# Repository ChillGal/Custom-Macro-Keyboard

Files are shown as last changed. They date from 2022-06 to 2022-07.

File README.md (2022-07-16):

# Custom-Macro-Keyboard
Custom designed macro keyboard

Thingiverse: https://www.thingiverse.com/thing:5415824

This was personal project for my partner as he is a streamer and the extra keys to bind to use is very useful while being cheaper than a Elgato stream deck.
- The case was designed in Autodesk Fusion 360.
- Code written in Arduino IDE.

## Part choice
For this project, I knew I wanted a display for text, a volume control knob and at least 8 buttons. The buttons also had to have a nice feeling so i went with Cherry MX Brown switches as they are my partner's favourite kind of switch. I used re-legendable keycaps to allow for relabelling the keycaps at a later date if necessary. The components used in this project are:
- Arduino Pro Micro (I specifically looked for a USB-C version since it is most robust than USB-B Micro and reversible connector)
- Rotary Encoders with threads (KY-040) to mount to the base plate
- Cherry MX Brown switches (I bought a pack of 30 for future project use)
- 0.91" OLED i2C module (Black & White)
- USB-C Female Breakout board (To mount to the Base)
- USB-C Male connector (To prevent wear and tear to the USB-C port built on the arduino)
- Solid core wire (Various colours to aid in organisation)
- M3 Screws (To mount the key plate)
- M3 Threaded Inserts (To allow the screws to mount)
- Rubber feet (to stop the keyboard moving so much when keys are pressed)

## Tools
To finish this project, the following tools were used which I consider essential:
- Soldering Iron
- 3D Printer (Creality CR-10S-Pro Stock) with PLA filament
- Screwdriver
- Wire cutters (Or scissors)
- A device capable of flashing code to the arduino
- Super Glue (for holding the display in place without moving)
- Heatshrink tubing (Prevent shorts)

Nice to haves:
- Label maker (For keycaps)
- Hot air gun (To soften the PLA and activate the heat shrink)
- Sandpaper (To give a nicer finish)
- 

## Design
The design of the case was done in Fusion Autodesk 360 over 8 iterations. It has an angle of 45&deg; for the keyplate with the keyplate while the display is mounted at a slightly steeper 60&deg; angle. The key spacing between the keys is to the Cherry specification of 19mm centre to centre.

### Keyboard base
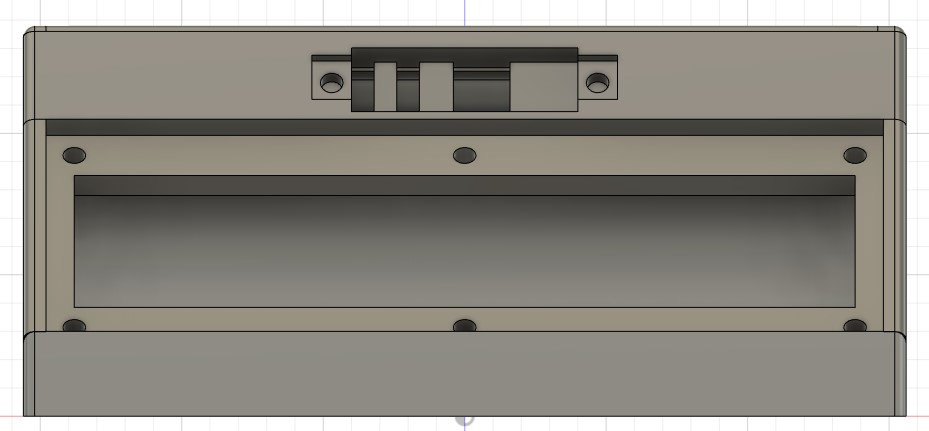
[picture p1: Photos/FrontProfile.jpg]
Front view of the base

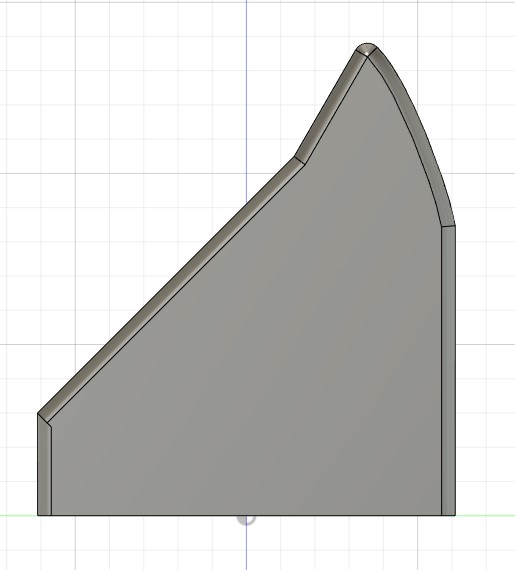
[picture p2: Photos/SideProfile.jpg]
Side view of the base

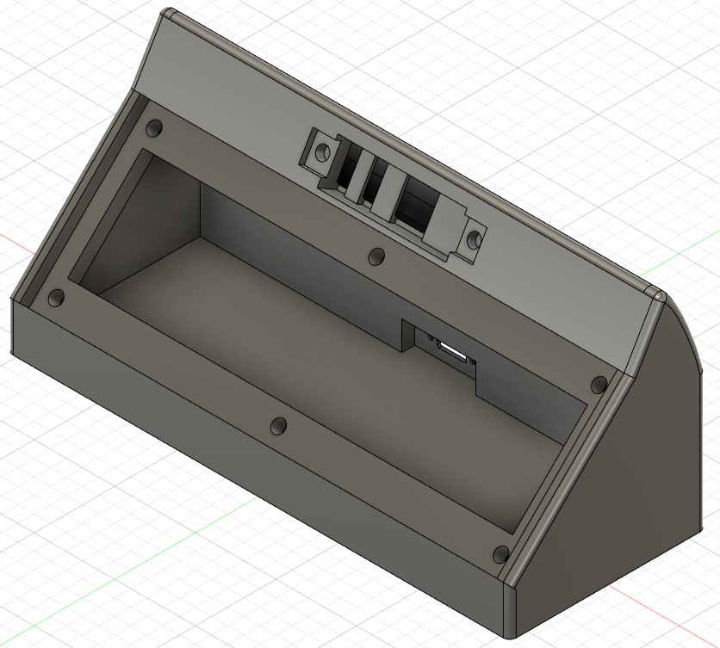
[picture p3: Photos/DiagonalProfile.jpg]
Diagonal view of the base

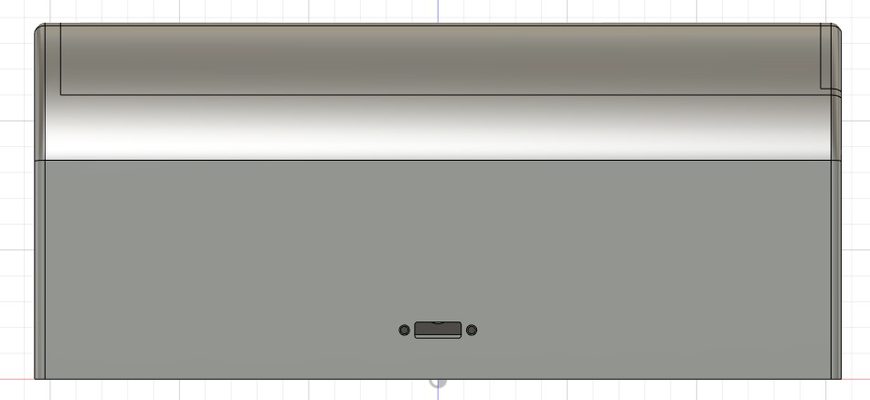
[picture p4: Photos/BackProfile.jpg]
Back view of the base


### Key plate
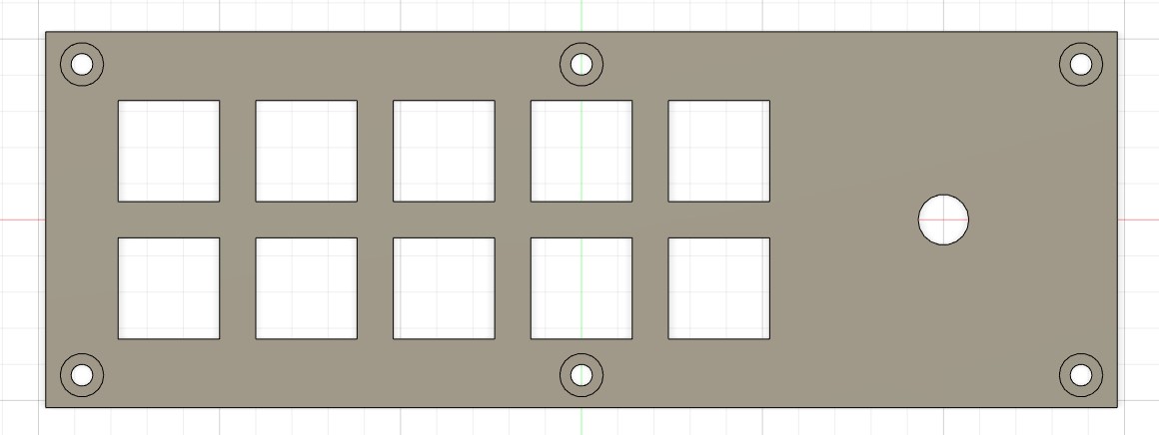
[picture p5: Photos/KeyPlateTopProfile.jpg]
Top view of the key plate

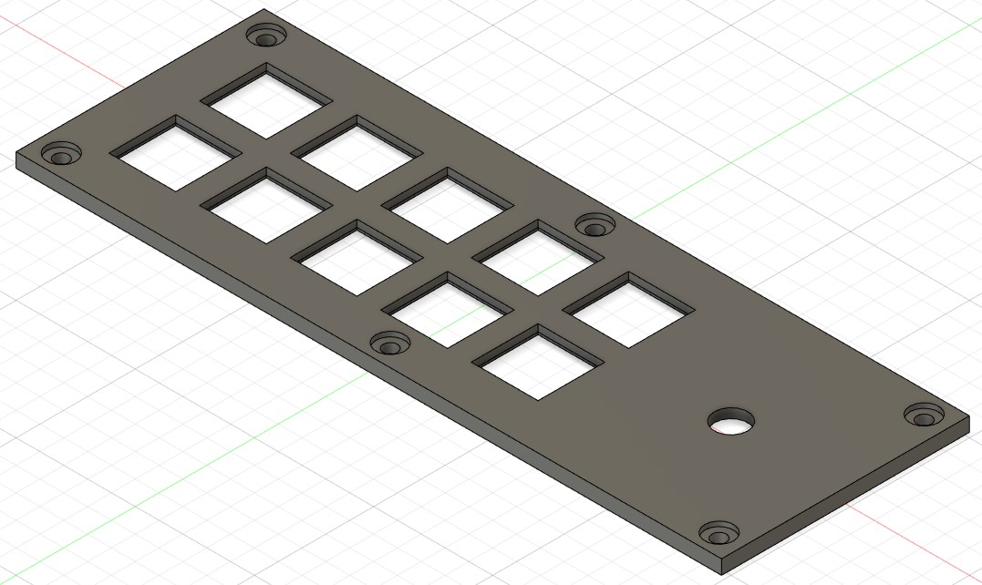
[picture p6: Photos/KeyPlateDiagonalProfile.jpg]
Diagonal view of the key plate


### Display plate
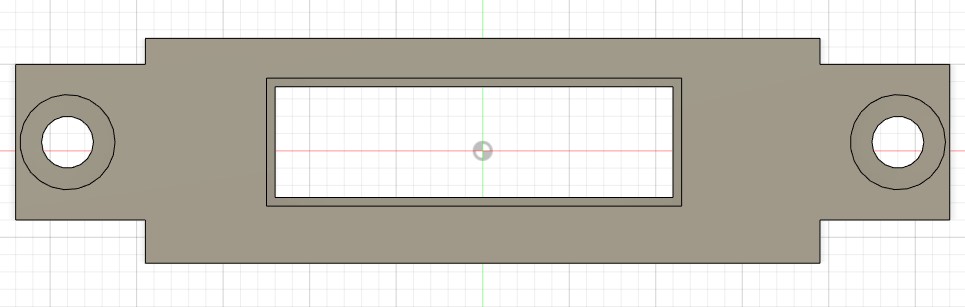
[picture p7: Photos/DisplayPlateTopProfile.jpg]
Top view of the display plate

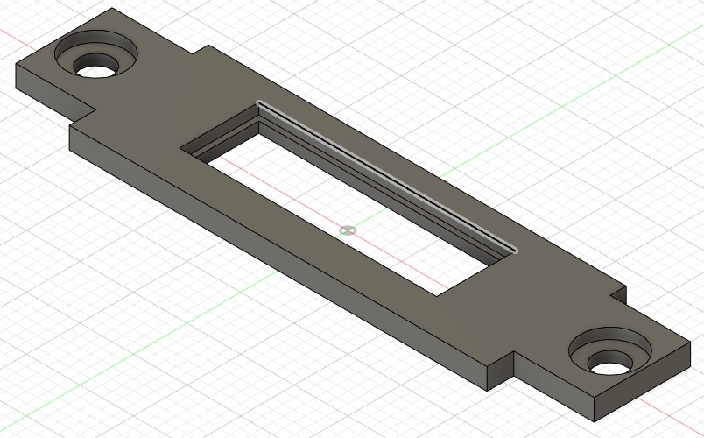
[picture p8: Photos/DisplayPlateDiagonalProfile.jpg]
Diagonal view of the display plate


## Printing the parts
This took a ridiculous amount of time at 18 hours to print for the base alone. The display plate took 20 minutes and the Keyplate took about 2$\frac{1}{2}$ hours resulting in a total print time of 20 hours and 50 minutes not including prototype prints. The base also printed with a lot of support which took a significant time to remove. In addition, I did not have good printer bed adhesion and as such used copious amount of glue to get the first layer to stick, however this glue resulted in lots of unevenness on the bottom which was luckily sorted out by the use of rubber feet on the corners.

## Soldering

### The arduino pins
I chose to solder pins rather than headers to the pcb so that i could easily hotswap it incase of failures since it is much easier to unplug 2 big headers than lots of small pins in order to take out the arduino. Another advantage is the size taken up by the pins which is significantly smaller height wise allowing to fit into the case without issue.

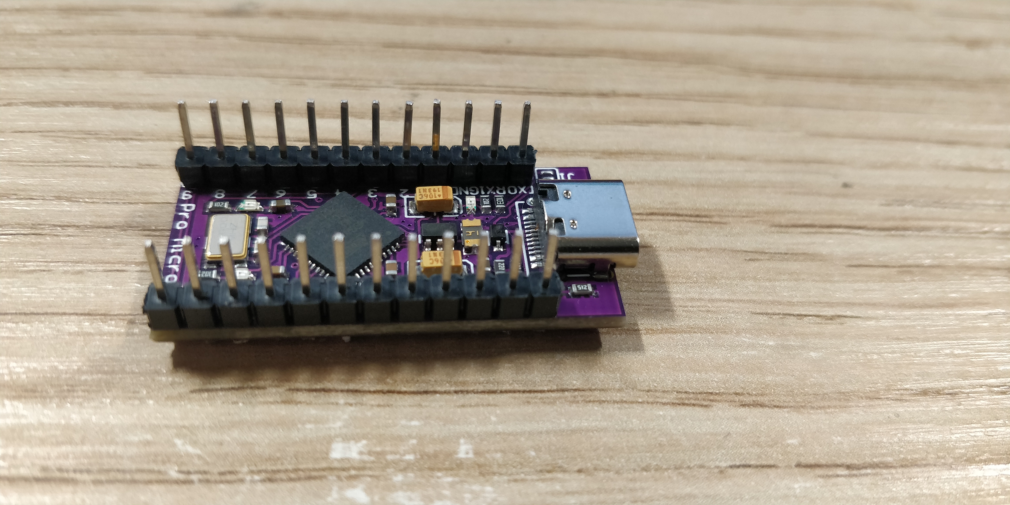
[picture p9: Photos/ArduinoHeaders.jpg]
Soldered Pins rather than headers

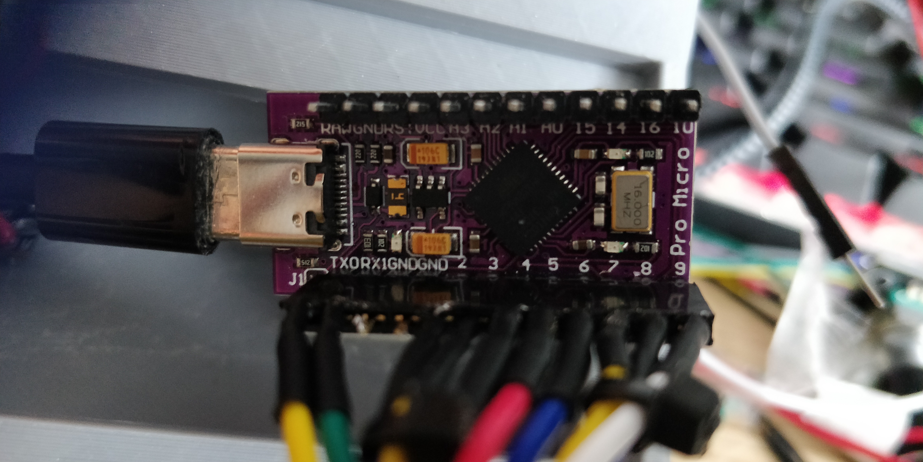
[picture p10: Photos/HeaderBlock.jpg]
A header block being used to connect the various parts of the project to the arduino

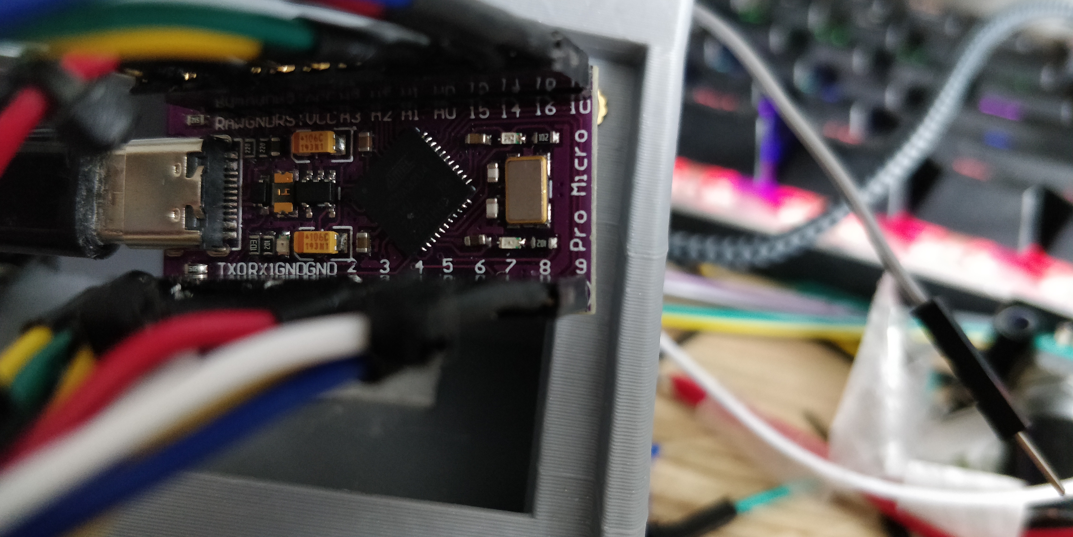
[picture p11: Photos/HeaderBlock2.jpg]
Closeup of headers blocks used


### Switch wiring
Initially all the switches were connected individually. However it was not a robust enough solution since the switch pins would fatigue from the constant movement and break easily. Therefore, I used solid core wire and twisted them together to make the entire assembly less prone to wear and be a lot stronger as a result. This also solved the issue of too many ground cables. The entire plate now just uses 1 ground connection which comes from the rotary encoder. Much better than 11 ground wires which I originally had. Each switch was connected to a pin on the pro micro which was pulled up and allowed for key press detection.

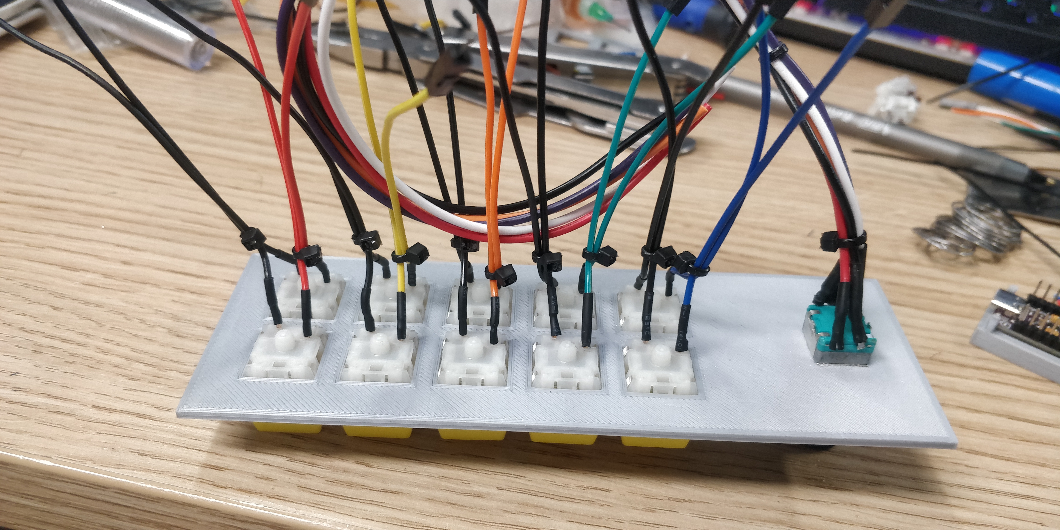
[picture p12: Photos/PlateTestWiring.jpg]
Initial Switch and enoder mounting with test leads

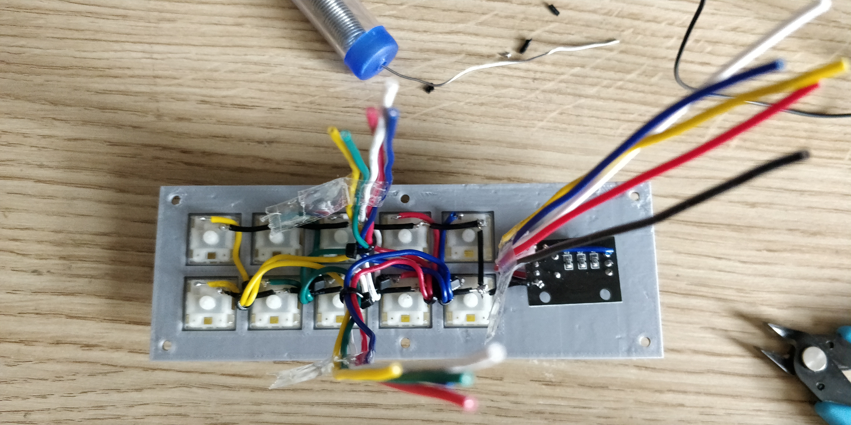
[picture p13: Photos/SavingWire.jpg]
Wires sorted into 3 bundles for top and bottom row and the encoder

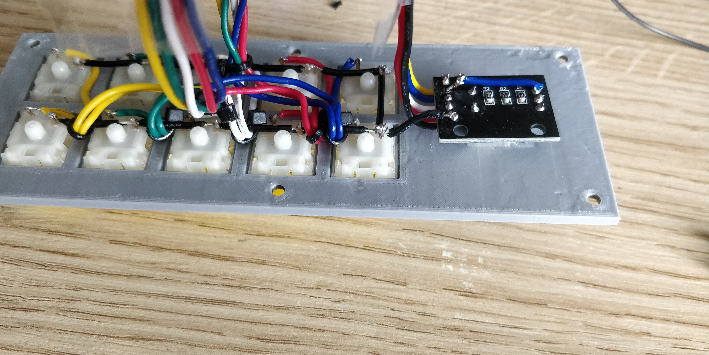
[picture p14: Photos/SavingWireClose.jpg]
Ground is shared across all buttons


### Display wiring
Since I had not fully assembled the project when I was testing the display, I used a header block to allow me to easily plug and unplug the display.

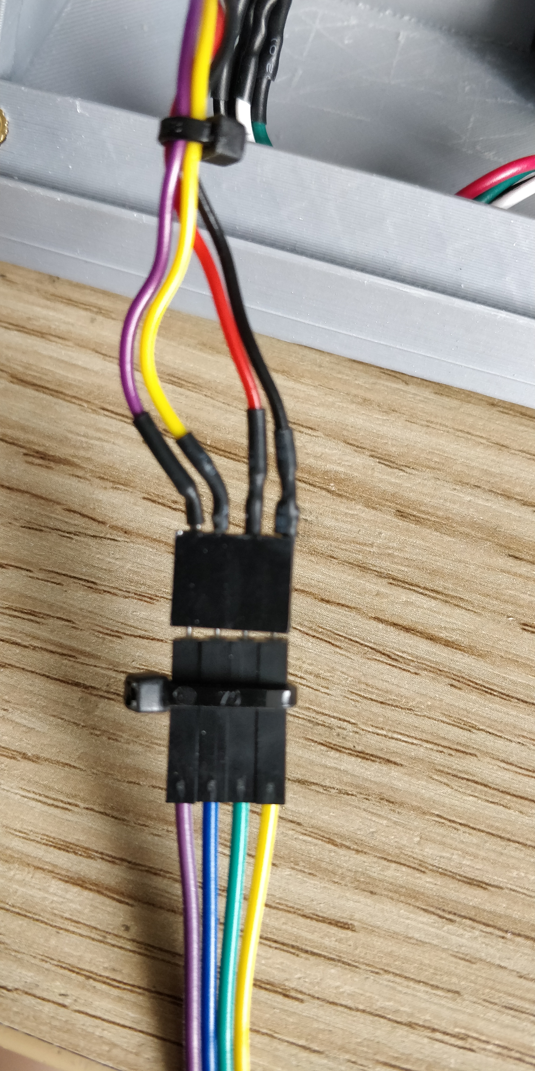
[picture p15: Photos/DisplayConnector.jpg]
Header connected to the display to allow for quick plug and unplugging


### USB wiring
Since the arduino only supports USB 2.0 Speeds, there is no point in increasing complexity and cost to get a USB 3.0 Type C connector.
From Left to right on the image below:
- Black = Ground
- Green = Data-
- White = Data+
- Red = 5V
USB-C Wiring

## Assembly

### Wiring
As a test fit, I tried putting everything in the base but the wires were too long so they needed to be shortened for the actual assembly.

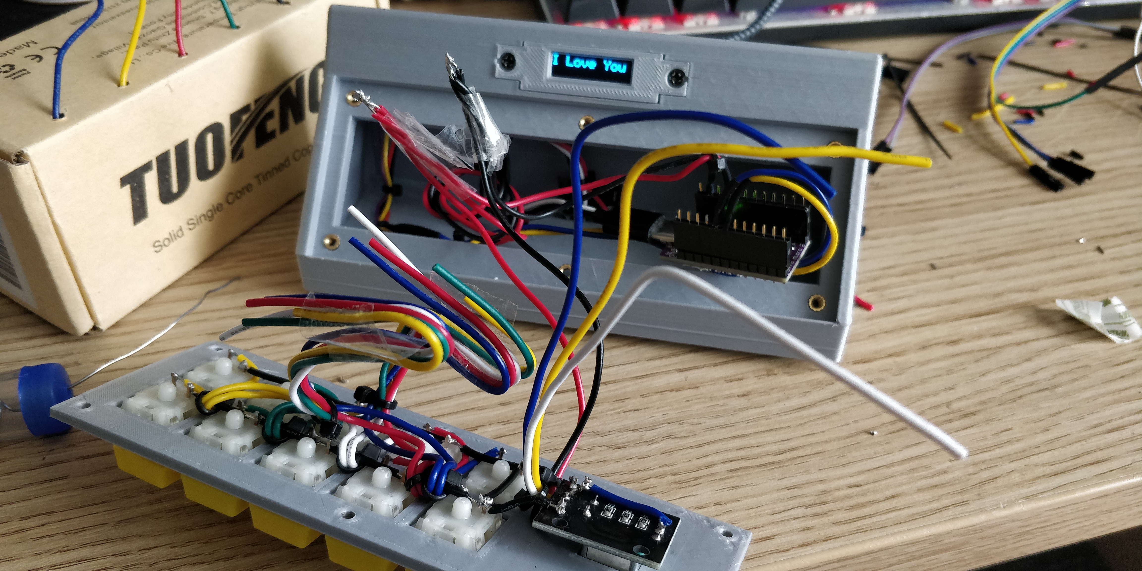
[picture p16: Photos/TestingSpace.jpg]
Trying to cram all the wires into the base


### Key plate
The switches fit snugly into the mounts and the encoder is secured with a washer and nut which is hidden beneath the knob. Screw holes were added to mount the plate to the base.

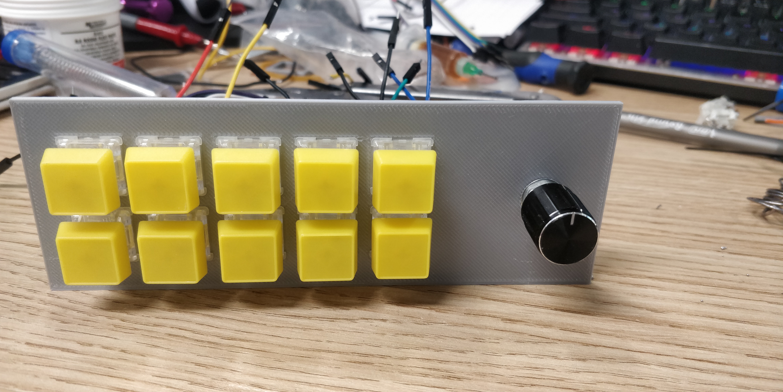
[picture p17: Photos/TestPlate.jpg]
Test fitting the keys and encoder

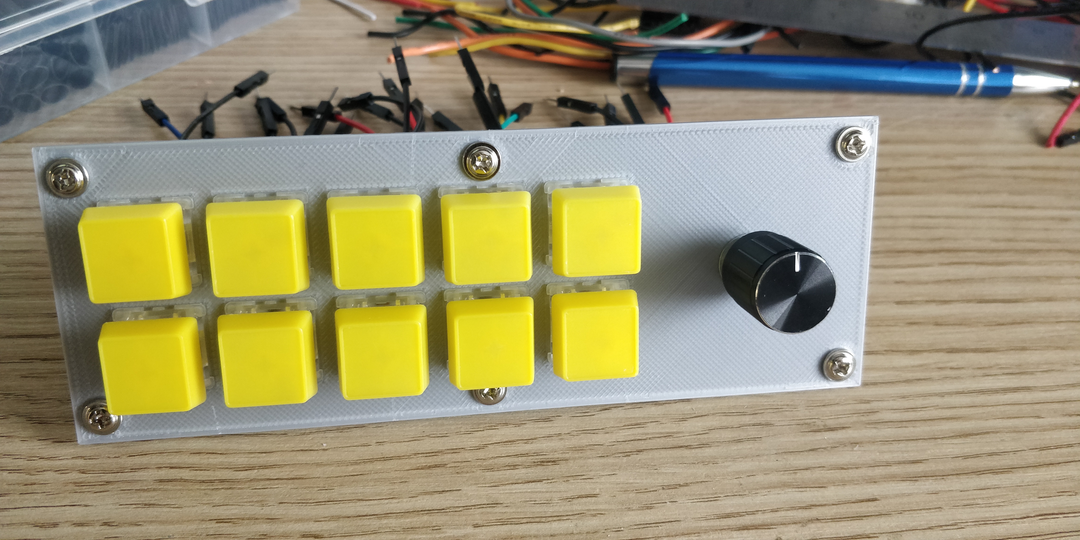
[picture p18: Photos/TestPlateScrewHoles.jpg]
Added screw holes which were later counter sunk to allow screws to sit flush


### Mounting the arduino
Since i had soldered the pins to the arduino, this came with some concerns. Mainly the worry that the pins could come in contact with a metal surface and short out which is particulary dangerous since it could kill the arduino. To prevent this, I came up with a small base plate that the arduino will slot into and sit on while the project was being developed. In the actual case, it is attached with some command strips between the pcb and the floor of the base.

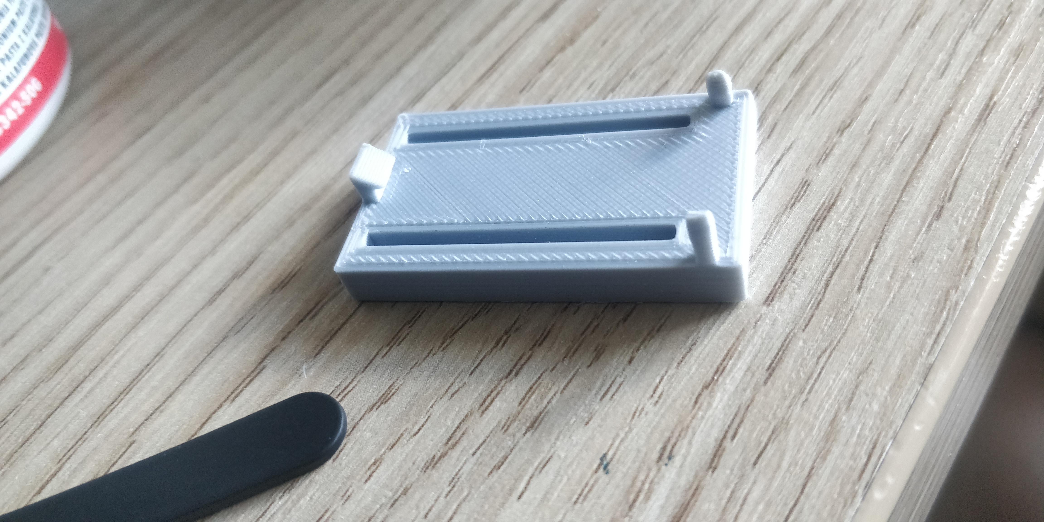
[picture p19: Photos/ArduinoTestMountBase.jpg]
Arduino was mounted in here

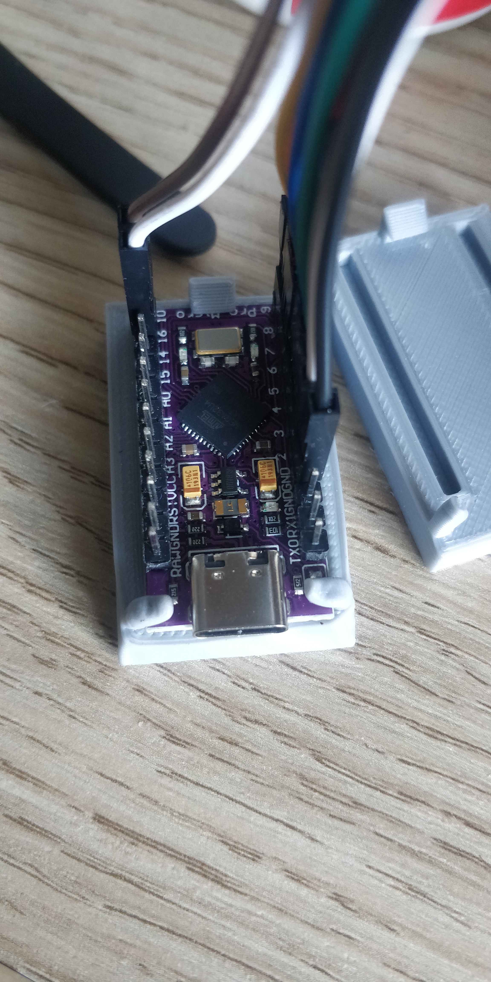
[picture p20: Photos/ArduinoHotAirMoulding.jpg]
A hot air gun was used to soften the PLA allowing me to manipulate it to a shape that holds the arduino more securely


## End Result
The final result of assembly. The screws were swapped out to smaller headed M3 threaded ones to allow for a flush fit. Personally, I think it looks better this way. Behind each screw is a threaded insert that was pushed into the PLA using the soldering iron.
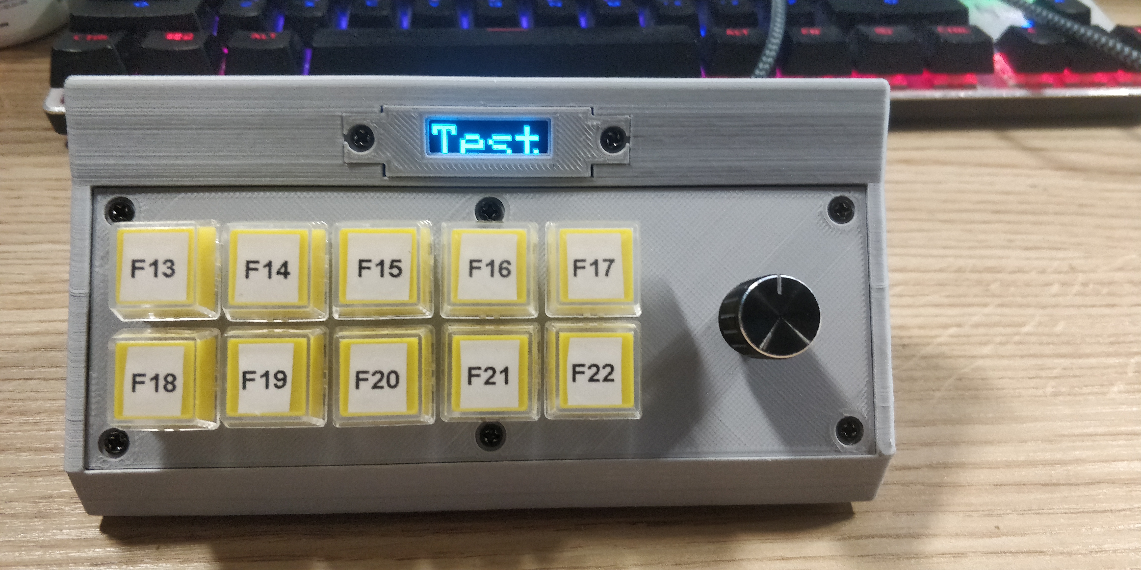
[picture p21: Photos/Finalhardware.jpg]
Final result


## Conclusion
Overall, this was a very fun project which was also very rewarding. However there are a number of things that I would change if I was to do this again, these being:
- The overall finish of the base should be smoother and the bottom should not be uneven to give a more appealing look.
- The weight of the base should be heavier to stop it moving around easily as the buttons and encoder are used.
- The angle of the buttons should be less agressive as it places quite a bit of stress on the wrist if used intensively for prolonged periods. 
- A bigger display which would allow for more details to be shown.

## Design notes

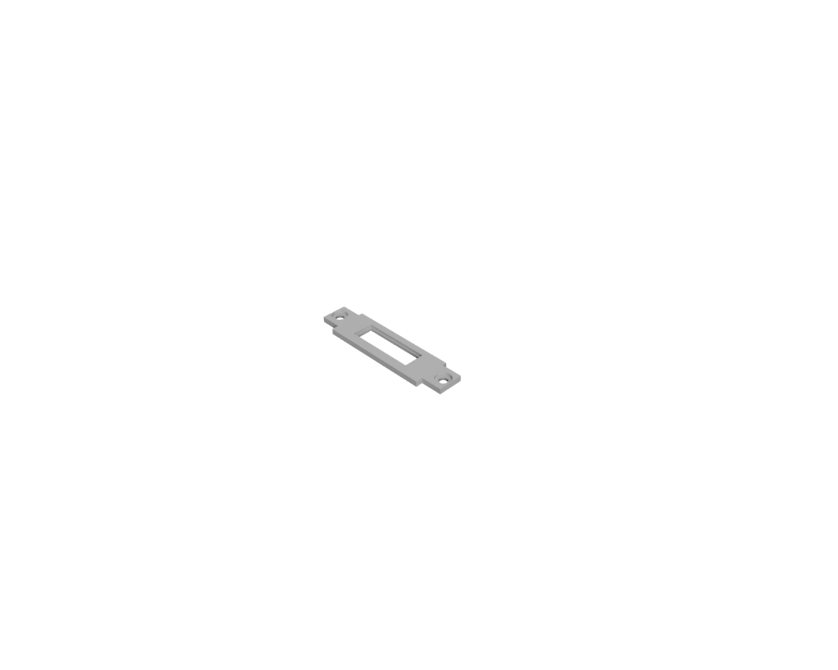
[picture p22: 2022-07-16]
Photos/DisplayPlateRender.png

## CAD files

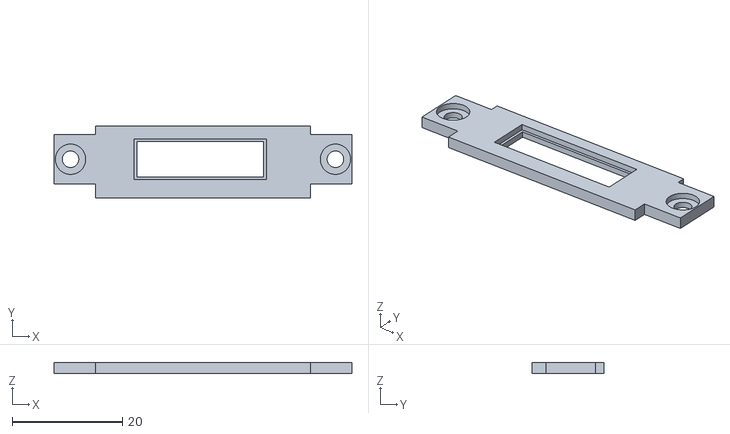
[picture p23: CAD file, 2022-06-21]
Macro-Keyboard-DisplayPlate.stl
54.0 x 13.0 x 2.00

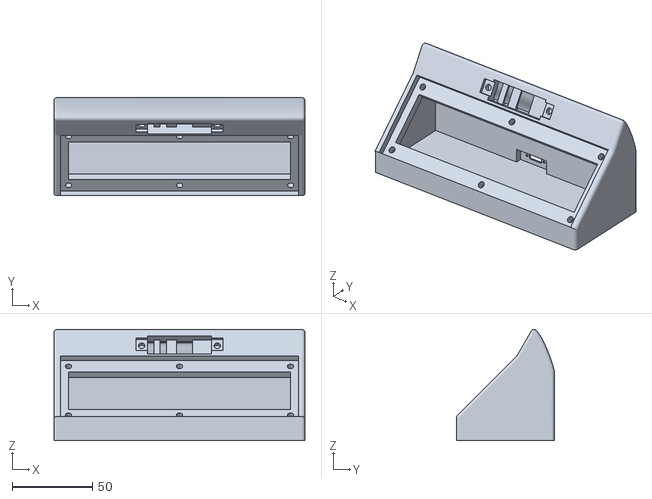
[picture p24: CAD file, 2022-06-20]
Macro-Keyboard-Base.stl
156.0 x 61.0 x 69.0

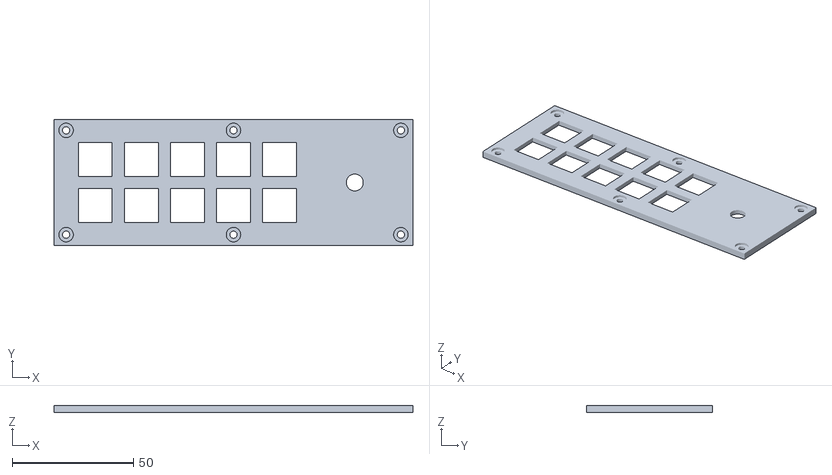
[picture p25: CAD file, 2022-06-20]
Macro-Keyboard-Keyplate.stl
148.0 x 52.0 x 3.00

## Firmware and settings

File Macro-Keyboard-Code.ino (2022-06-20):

#include <Adafruit_GFX.h>
#include <Adafruit_SSD1306.h>
#include <HID-Project.h>
#include <SPI.h>
#include <Wire.h>

/*
 * ARDUINO PRO MICRO PINOUT
 * PIN 1  - Button - Top Row - F13
 * PIN 0  - Button - Top Row - F14
 * PIN 2  - I2C - SDA - Display
 * PIN 3  - I2C - SCL - Display
 * PIN 4  - Button - Top Row - F15
 * PIN 5  - Button - Top Row - F16
 * PIN 6  - Button - Top Row - F17
 * PIN 7  - Rotary Encoder - CLK
 * PIN 8  - Rotary Encoder - DT
 * PIN 9  - Rotary Encoder - SW
 * PIN 10 - Button - Bottom Row - F
 * PIN 16 - Button - Bottom Row - F
 * PIN 14 - Button - Bottom Row - F
 * PIN 15 - Button - Bottom Row - F
 * PIN 18 - Button - Bottom Row - F
*/

/*
    KEY_F13 - 0x68
    KEY_F14 - 0x69
    KEY_F15 - 0x6A
    KEY_F16 - 0x6B
    KEY_F17 - 0x6C
    KEY_F18 - 0x6D
    KEY_F19 - 0x6E
    KEY_F20 - 0x6F
    KEY_F21 - 0x70
    KEY_F22 - 0x71
    KEY_F23 - 0x72
    KEY_F24 - 0x73
*/

//Definitions
  //Keyboard layout
#define HID_CUSTOM_LAYOUT
#define LAYOUT_UNITED_KINGDOM
  //Display
#define SCREEN_WIDTH 128 // Screen width
#define SCREEN_HEIGHT 32 //Screen height
#define LOGO_WIDTH 128 // Logo width
#define LOGO_HEIGHT 32 //Logo height
#define OLED_RESET 4 // OLED reset pin
#define SCREEN_ADDRESS 0x3C // I2C address
  //Encoder                                                                  
#define ENC_CLK 7 //Encoder clock
#define ENC_DT 8 //Encoder data
#define ENC_SW 9 // Encoder switch
  //Buttons
#define BTN_F13 1 //F13 @ Pin 1
#define BTN_F14 0 //F14 @ Pin 0
#define BTN_F15 4 //F15 @ Pin 4
#define BTN_F16 5 //F16 @ Pin 5
#define BTN_F17 6 //F17 @ Pin 6
#define BTN_F18 18 //F18 @ Pin 18
#define BTN_F19 15 //F19 @ Pin 15
#define BTN_F20 14 //F20 @ Pin 14
#define BTN_F21 16 //F21 @ Pin 16
#define BTN_F22 10 //F22 @ Pin 10
  //Keys
#define K_F13 KEY_F13
#define K_F14 KEY_F14
#define K_F15 KEY_F15
#define K_F16 KEY_F16
#define K_F17 KEY_F17
#define K_F18 KEY_F18
#define K_F19 KEY_F19
#define K_F20 KEY_F20
#define K_F21 KEY_F21
#define K_F22 KEY_F22

//Bitmap
static const unsigned char PROGMEM Startup_Logo_BMP[] = {
0xFF, 0xFF, 0xFF, 0xFF, 0xFF, 0xFF, 0xFF, 0xFF, 0xFF, 0xFF, 0xFF, 0xFF, 0xFF, 0xFF, 0xFF, 0xFF,
0x80, 0x00, 0x00, 0x00, 0x00, 0x00, 0x00, 0x00, 0x00, 0x00, 0x00, 0x00, 0x00, 0x00, 0x00, 0x01,
0xBF, 0xFF, 0xFF, 0xFF, 0xFF, 0xFF, 0xFF, 0xFF, 0xFF, 0xFF, 0xFF, 0xFF, 0xFF, 0xFF, 0xFF, 0xFD,
0xA0, 0x00, 0x00, 0x00, 0x00, 0x00, 0x00, 0x00, 0x00, 0x00, 0x00, 0x00, 0x00, 0x00, 0x00, 0x05,
0xAF, 0xFF, 0xFF, 0xFF, 0xFF, 0xFF, 0xFF, 0xFF, 0xFF, 0xFF, 0xFF, 0xFF, 0xFF, 0xFF, 0xFF, 0xF5,
0xA8, 0x00, 0x00, 0x00, 0x00, 0x00, 0x00, 0x00, 0x00, 0x00, 0x00, 0x00, 0x00, 0x00, 0x00, 0x15,
0xAB, 0xFF, 0xFF, 0xFF, 0xFF, 0xFF, 0xFF, 0xFF, 0xFF, 0xFF, 0xFF, 0xFF, 0xFF, 0xFF, 0xFF, 0xD5,
0xAA, 0x00, 0x00, 0x00, 0x00, 0x00, 0x00, 0x00, 0x00, 0x00, 0x00, 0x00, 0x00, 0x00, 0x00, 0x55,
0xAA, 0xFF, 0xFF, 0xFF, 0xFF, 0xFF, 0xFF, 0xFF, 0xFF, 0xFF, 0xFF, 0xFF, 0xFF, 0xFF, 0xFF, 0x55,
0xAA, 0x80, 0x00, 0x00, 0x00, 0x00, 0x00, 0x00, 0x00, 0x00, 0x00, 0x00, 0x00, 0x00, 0x01, 0x55,
0xAA, 0xBF, 0xFF, 0xFF, 0xFF, 0xFF, 0xFF, 0xFF, 0xFF, 0xFF, 0xFF, 0xFF, 0xFF, 0xFF, 0xFD, 0x55,
0xAA, 0xA0, 0x00, 0x00, 0x00, 0x00, 0x00, 0x00, 0x00, 0x00, 0x00, 0x00, 0x00, 0x00, 0x05, 0x55,
0xAA, 0xAF, 0xFF, 0xFF, 0xFF, 0xFF, 0xFF, 0xFF, 0xFF, 0xFF, 0xFF, 0xFF, 0xFF, 0xFF, 0xF5, 0x55,
0xAA, 0xA8, 0x00, 0x00, 0x00, 0x00, 0x00, 0x00, 0x00, 0x00, 0x00, 0x00, 0x00, 0x00, 0x15, 0x55,
0xAA, 0xAB, 0xFF, 0xFF, 0xFF, 0xFF, 0xFF, 0xFF, 0xFF, 0xFF, 0xFF, 0xFF, 0xFF, 0xFF, 0xD5, 0x55,
0xAA, 0xAA, 0x00, 0x00, 0x00, 0x00, 0x00, 0x00, 0x00, 0x00, 0x00, 0x00, 0x00, 0x00, 0x55, 0x55,
0xAA, 0xAA, 0x00, 0x00, 0x00, 0x00, 0x00, 0x00, 0x00, 0x00, 0x00, 0x00, 0x00, 0x00, 0x55, 0x55,
0xAA, 0xAB, 0xFF, 0xFF, 0xFF, 0xFF, 0xFF, 0xFF, 0xFF, 0xFF, 0xFF, 0xFF, 0xFF, 0xFF, 0xD5, 0x55,
0xAA, 0xA8, 0x00, 0x00, 0x00, 0x00, 0x00, 0x00, 0x00, 0x00, 0x00, 0x00, 0x00, 0x00, 0x15, 0x55,
0xAA, 0xAF, 0xFF, 0xFF, 0xFF, 0xFF, 0xFF, 0xFF, 0xFF, 0xFF, 0xFF, 0xFF, 0xFF, 0xFF, 0xF5, 0x55,
0xAA, 0xA0, 0x00, 0x00, 0x00, 0x00, 0x00, 0x00, 0x00, 0x00, 0x00, 0x00, 0x00, 0x00, 0x05, 0x55,
0xAA, 0xBF, 0xFF, 0xFF, 0xFF, 0xFF, 0xFF, 0xFF, 0xFF, 0xFF, 0xFF, 0xFF, 0xFF, 0xFF, 0xFD, 0x55,
0xAA, 0x80, 0x00, 0x00, 0x00, 0x00, 0x00, 0x00, 0x00, 0x00, 0x00, 0x00, 0x00, 0x00, 0x01, 0x55,
0xAA, 0xFF, 0xFF, 0xFF, 0xFF, 0xFF, 0xFF, 0xFF, 0xFF, 0xFF, 0xFF, 0xFF, 0xFF, 0xFF, 0xFF, 0x55,
0xAA, 0x00, 0x00, 0x00, 0x00, 0x00, 0x00, 0x00, 0x00, 0x00, 0x00, 0x00, 0x00, 0x00, 0x00, 0x55,
0xAB, 0xFF, 0xFF, 0xFF, 0xFF, 0xFF, 0xFF, 0xFF, 0xFF, 0xFF, 0xFF, 0xFF, 0xFF, 0xFF, 0xFF, 0xD5,
0xA8, 0x00, 0x00, 0x00, 0x00, 0x00, 0x00, 0x00, 0x00, 0x00, 0x00, 0x00, 0x00, 0x00, 0x00, 0x15,
0xAF, 0xFF, 0xFF, 0xFF, 0xFF, 0xFF, 0xFF, 0xFF, 0xFF, 0xFF, 0xFF, 0xFF, 0xFF, 0xFF, 0xFF, 0xF5,
0xA0, 0x00, 0x00, 0x00, 0x00, 0x00, 0x00, 0x00, 0x00, 0x00, 0x00, 0x00, 0x00, 0x00, 0x00, 0x05,
0xBF, 0xFF, 0xFF, 0xFF, 0xFF, 0xFF, 0xFF, 0xFF, 0xFF, 0xFF, 0xFF, 0xFF, 0xFF, 0xFF, 0xFF, 0xFD,
0x80, 0x00, 0x00, 0x00, 0x00, 0x00, 0x00, 0x00, 0x00, 0x00, 0x00, 0x00, 0x00, 0x00, 0x00, 0x01,
0xFF, 0xFF, 0xFF, 0xFF, 0xFF, 0xFF, 0xFF, 0xFF, 0xFF, 0xFF, 0xFF, 0xFF, 0xFF, 0xFF, 0xFF, 0xFF
};

//Variables
int ENC_PrevState; //Previous encoder state
int ENC_CurrentState; //Current encoder state
int ENC_PBState; //Previous encoder button state
int ENC_CBState; //Current encoder button state
int ENC_Toggle; //Toggle switch to avoid spamming on button hold
int ENC_Mute; //Mute option to disable volume control if muted
unsigned long currentTime = 0; //Current time
unsigned long clearDisplayTime = 0; //Time until display needs clearing
static uint8_t prevNextCode = 0; //Encoder debouncing
static int8_t val; //Encoder value
static uint16_t store=0; //Encoder debouncing

//Display initialisation
Adafruit_SSD1306 display(SCREEN_WIDTH, SCREEN_HEIGHT, &Wire, OLED_RESET);

//Button class
class button {
  public:
  const KeyboardKeycode key; //HID-Project uses a "KeyboardKeycode" with Enum
  const uint8_t pin;
  button(KeyboardKeycode k, uint8_t p) : key(k), pin(p){}

  //Debouncing and key press handling
  void press(boolean state){ 
    if(state == pressed || (millis() - lastPressed  <= debounceTime)){
      return;
    }
    lastPressed = millis();
    state ? Keyboard.press(key) : Keyboard.release(key);    
    pressed = state;
    if(state == pressed) {
      display.clearDisplay();
      display.setTextColor(SSD1306_WHITE);
      display.setTextSize(2);
      display.setCursor(0, 0);
      display.cp437(true);  
      switch(key){
        case 104:
          display.print("F13");
          break;
        case 105:
          display.print("F14");
          break;
        case 106:
          display.print("F15");
          break;
        case 107:
          display.print("F16");
          break;
        case 108:
          display.print("F17");
          break;
        case 109:
          display.print("F18");
          break;
        case 110:
          display.print("F19");
          break;
        case 111:
          display.print("F20");
          break;
        case 112:
          display.print("F21");
          break;
        case 113:
          display.print("F22");
          break;
      }
      display.display();
      clearDisplayTime = millis();
    }
  }
  //Read digital pin and get inverse
  void update(){
    press(!digitalRead(pin)); 
  }
  private:
  const unsigned long debounceTime = 30;
  unsigned long lastPressed = 0;
  boolean pressed = 0;
};

//Button array
button buttons[] = {
  {K_F13, BTN_F13},
  {K_F14, BTN_F14},
  {K_F15, BTN_F15},
  {K_F16, BTN_F16},
  {K_F17, BTN_F17},
  {K_F18, BTN_F18},
  {K_F19, BTN_F19},
  {K_F20, BTN_F20},
  {K_F21, BTN_F21},
  {K_F22, BTN_F22}
};

const uint8_t NumButtons = sizeof(buttons) / sizeof(button); //Number of buttons

void setup() {

  //Initialisation
  Serial.begin(9600);
  Consumer.begin();
	Keyboard.begin();

  //Pins
    //Buttons
    for(int i = 0; i < NumButtons; i++){
      pinMode(buttons[i].pin, INPUT_PULLUP);
    }
    //Rotary Encoder
  pinMode(ENC_CLK,INPUT_PULLUP);
	pinMode(ENC_DT,INPUT_PULLUP);
	pinMode(ENC_SW,INPUT_PULLUP);
    //Turn LEDs off
  pinMode(LED_BUILTIN_TX,INPUT);
  pinMode(LED_BUILTIN_RX,INPUT);
    
  //Check for display
  CheckDisplayExists();

  //Get initial state of encoder
  ENC_PrevState = digitalRead(ENC_CLK);
  ENC_PBState = digitalRead(ENC_SW);
  
  //Display initial image
  StartupBMP();
  delay(2000);
  ClearDisplay();
}

void loop() {
//Get current time
currentTime = millis();
//Check how long since displayed, if over 5 seconds, then clear the display.
if(clearDisplayTime == (currentTime - 5000)) {
  ClearDisplay();
  clearDisplayTime = 0;
}
//Check button presses
  for(int i = 0; i < NumButtons; i++){
    buttons[i].update();
  }
//Rotary Encoder 
 if( val=read_rotary() ) {
    if ( prevNextCode==0x0b) {
      RotaryEncoderLeft();
      clearDisplayTime = millis();
    }
    if ( prevNextCode==0x07) {
      RotaryEncoderRight();
      clearDisplayTime = millis();
    }
  }

//Check encoder button state
  if((digitalRead(ENC_SW) != ENC_PBState) && (ENC_Toggle != 1)) {
    RotaryEncoderPress();
    clearDisplayTime = millis();
    ENC_Toggle = 1;
    }

  if((digitalRead(ENC_SW) == ENC_PBState) && (ENC_Toggle == 1)) {
    ENC_Toggle = 0;
    }
}

//Check for display
void CheckDisplayExists() {
  //Checks if display exists, if not continues checking until display found
  if(!display.begin(SSD1306_SWITCHCAPVCC, SCREEN_ADDRESS)) {
    Serial.println(F("SSD1306 allocation failed"));
    delay(5000); //5 Seconds between checks
    CheckDisplayExists();
  }
}
//Startup bitmap
void StartupBMP() {
  display.clearDisplay();
  display.setCursor(0, 0);
  display.drawBitmap(
    (display.width() - LOGO_WIDTH) / 2,
    (display.height() - LOGO_HEIGHT) / 2,
     Startup_Logo_BMP, LOGO_WIDTH, LOGO_HEIGHT, 1);
  display.display();
}
//Clear display
void ClearDisplay() {
  display.clearDisplay();
  display.display();
}
//Rotary encoder
void RotaryEncoderRight() {
  //Volume UP
  Consumer.write(MEDIA_VOLUME_UP);
  display.clearDisplay();
  display.setTextColor(SSD1306_WHITE);
  display.setTextSize(2);
  display.setCursor(0, 0);
  display.cp437(true);  
  display.print(F("VOL UP"));
  display.display();
}  
void RotaryEncoderLeft() {
  //Volume DOWN
  Consumer.write(MEDIA_VOLUME_DOWN);
  display.clearDisplay();
  display.setTextColor(SSD1306_WHITE);
  display.setTextSize(2);
  display.setCursor(0, 0);
  display.cp437(true);  
  display.print(F("VOL DOWN"));
  display.display();
}
void RotaryEncoderPress() {
  //Volume MUTE
  Consumer.write(MEDIA_VOL_MUTE);
  display.clearDisplay();
  display.setTextColor(SSD1306_WHITE);
  display.setTextSize(2);
  display.setCursor(0, 0);
  display.cp437(true);  
  display.print("MUTE");
  display.display();
}

//Read noisy input and debounce
int8_t read_rotary() {
  static int8_t rot_enc_table[] = {0,1,1,0,1,0,0,1,1,0,0,1,0,1,1,0};

  prevNextCode <<= 2;
  if (digitalRead(ENC_DT)) prevNextCode |= 0x02;
  if (digitalRead(ENC_CLK)) prevNextCode |= 0x01;
  prevNextCode &= 0x0f;

   // If valid then store as 16 bit data.
   if  (rot_enc_table[prevNextCode] ) {
      store <<= 4;
      store |= prevNextCode;
      //if (store==0xd42b) return 1;
      //if (store==0xe817) return -1;
      if ((store&0xff)==0x2b) return -1;
      if ((store&0xff)==0x17) return 1;
   }
   return 0;
}

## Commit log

2022-06-20 3D design, Code + photos
    [Macro-Keyboard-Base.stl, Macro-Keyboard-Keyplate.stl]
2022-06-21 Cad files
    [Macro-Keyboard-DisplayPlate.stl]
